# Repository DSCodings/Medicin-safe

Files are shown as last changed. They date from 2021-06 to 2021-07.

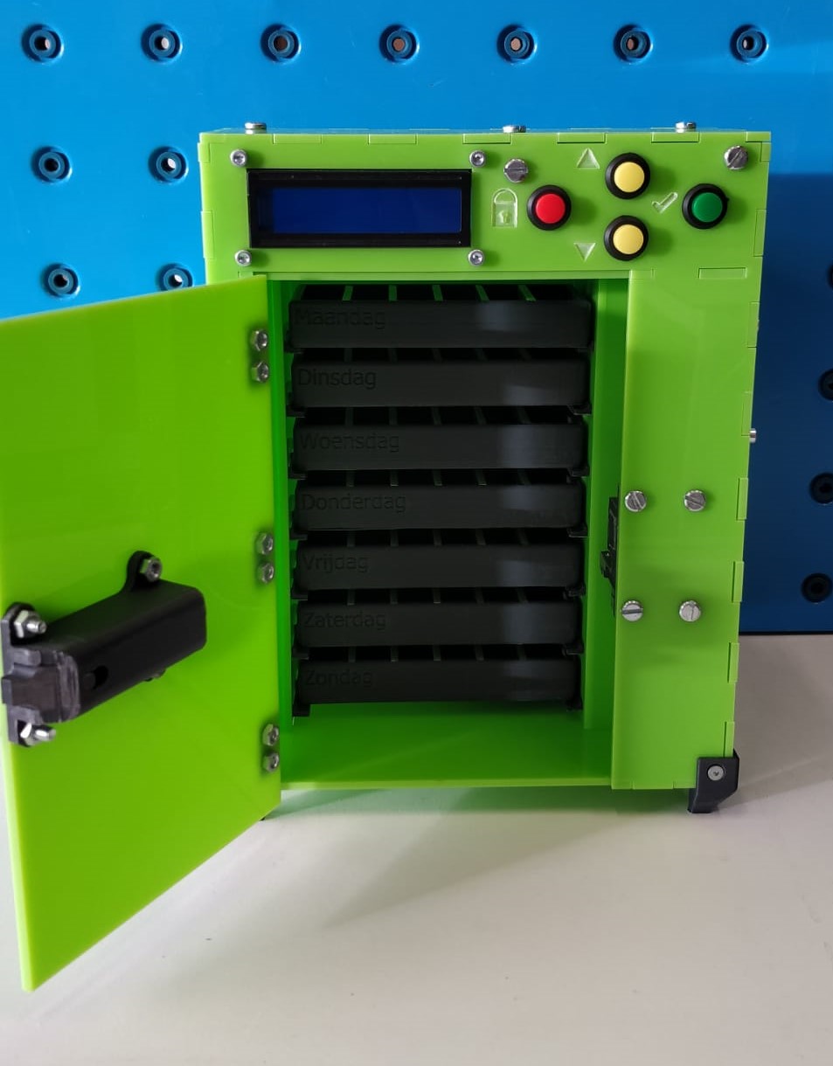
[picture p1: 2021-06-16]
English/photos/Foto1.jpeg

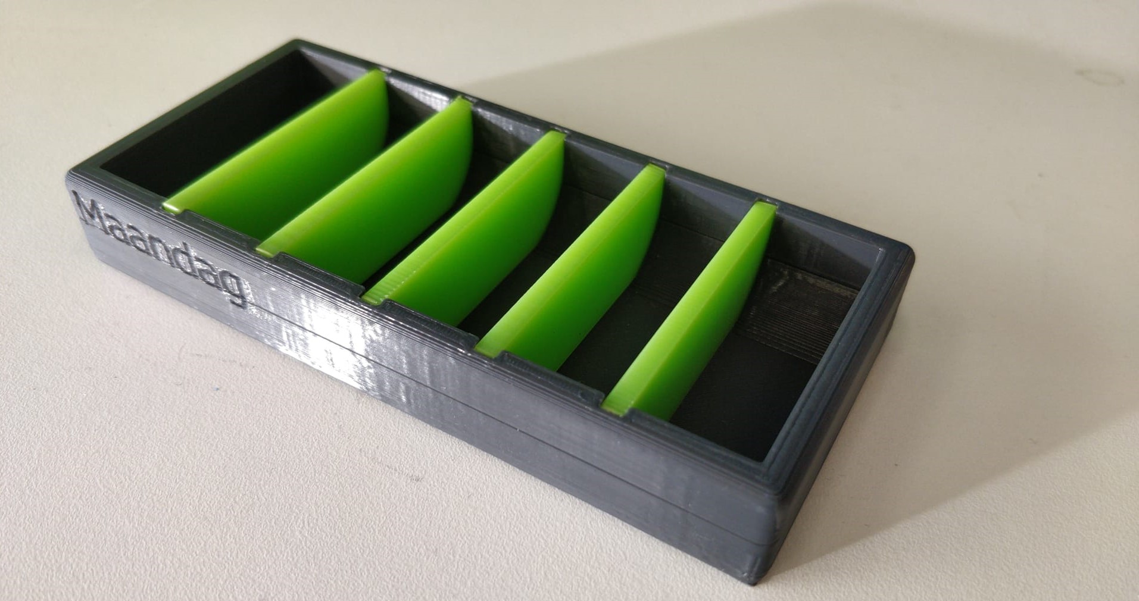
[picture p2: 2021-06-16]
English/photos/Foto3.jpeg

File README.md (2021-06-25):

# Medicijnenkluisje
Het project van een medicijnen kluisje dat gemaakt is in school. 
Je kan alle informatie vinden van stappenplan tot elektrisch schema tot video's wat het is.
Je kan de video's hier vinden:
https://www.youtube.com/watch?v=T6DbwzbS6sM
https://www.youtube.com/watch?v=bsVCNl2Fkfo

The project of a medicine locker made in school.
You can find all information from step-by-step plan to electrical diagram to videos what it is.
You can find the videos here:
https://www.youtube.com/watch?v=T6DbwzbS6sM
https://www.youtube.com/watch?v=bsVCNl2Fkfo

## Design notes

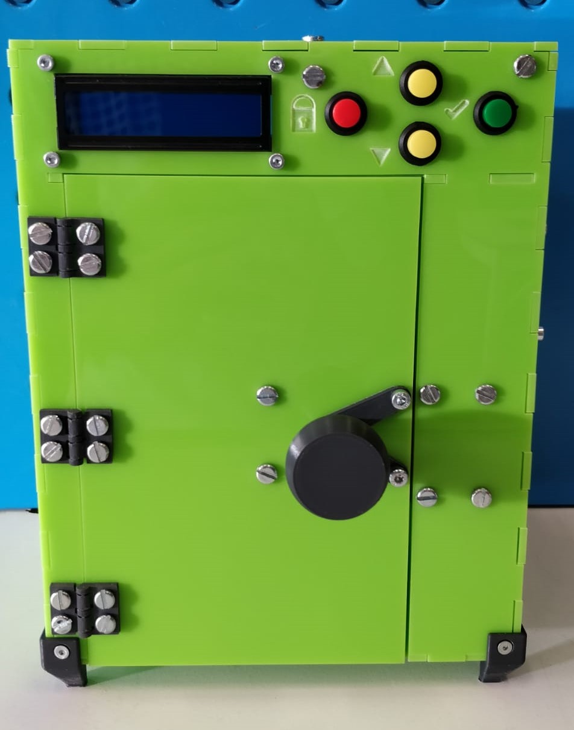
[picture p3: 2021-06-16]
English/photos/Foto2.jpeg

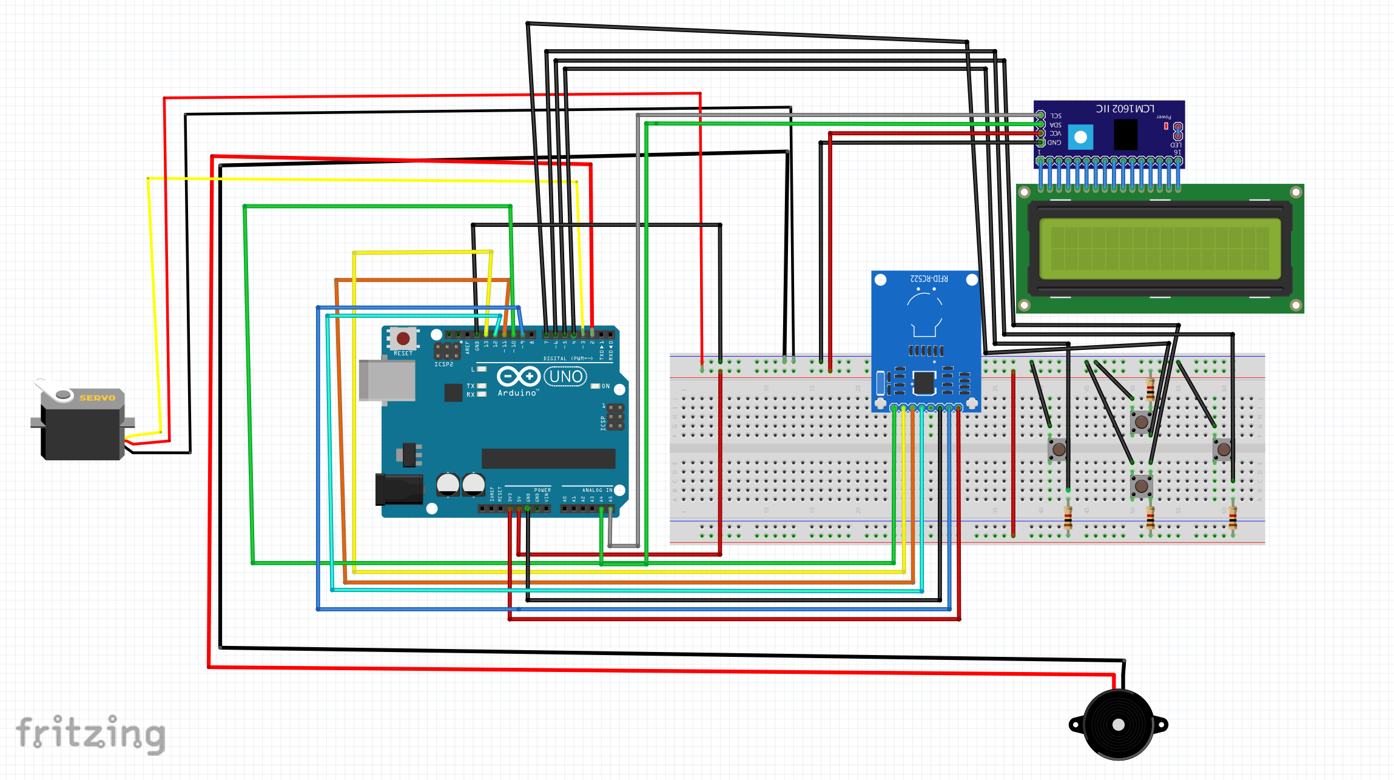
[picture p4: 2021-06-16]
English/electric scheme/Elektric scheme.png

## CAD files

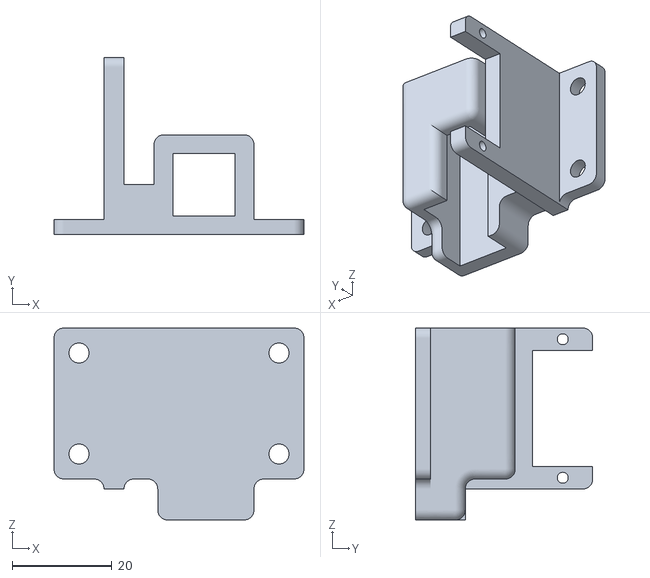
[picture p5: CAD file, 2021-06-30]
English/Files/3D printer STL files/16 slot servo holder.stl
50.0 x 35.5 x 38.4

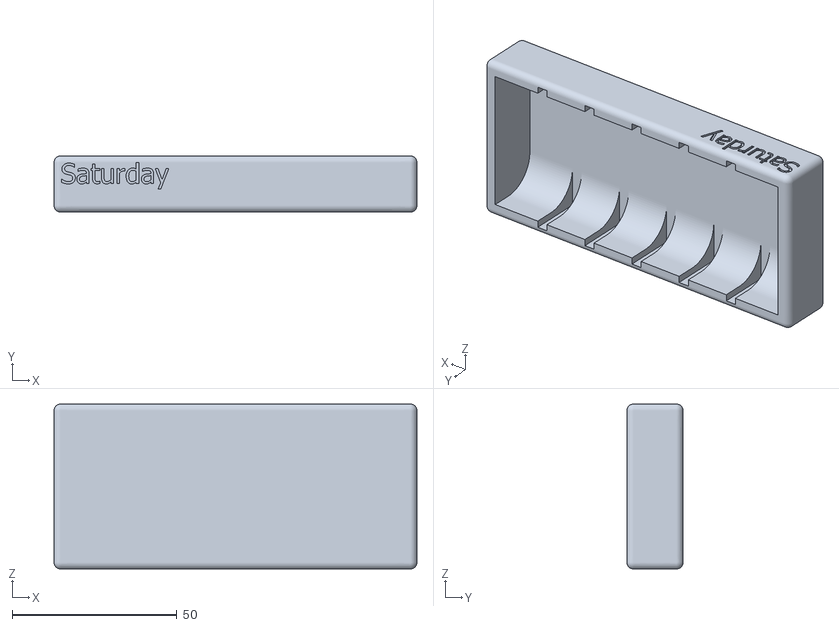
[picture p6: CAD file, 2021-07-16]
English/Files/3D printer STL files/Trays/Saturday.stl
110.0 x 17.0 x 50.0

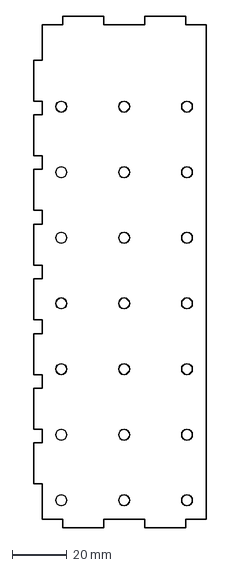
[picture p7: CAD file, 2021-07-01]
English/Files/Lazer DXF files/2 inner side plate.dxf
63.0 x 187.0 mm

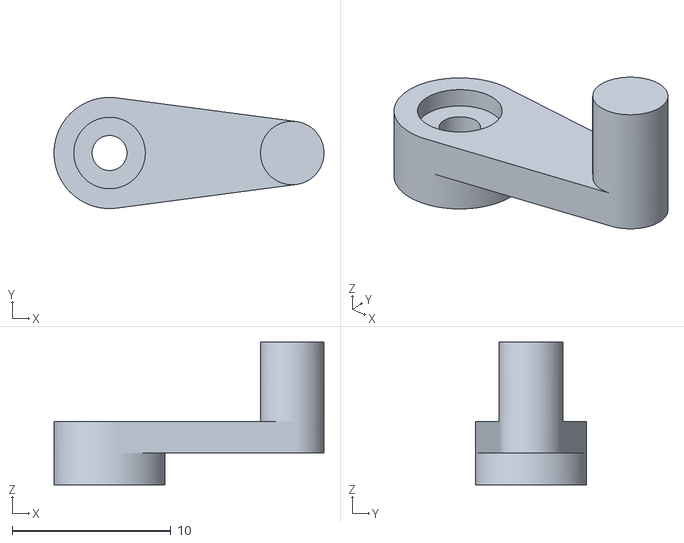
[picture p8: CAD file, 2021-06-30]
Nederlands/Bestanden/3D printer STL files/27 servo arm.stl
17.0 x 7.00 x 9.00

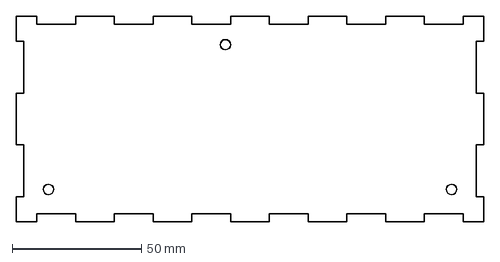
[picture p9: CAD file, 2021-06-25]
Nederlands/Bestanden/Lazer DXF files/12 boven plaat LCD.dxf
181.0 x 79.5 mm

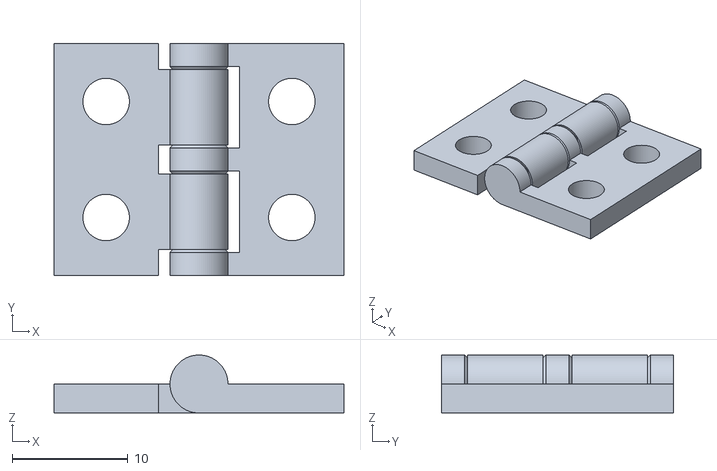
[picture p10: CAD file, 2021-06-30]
English/Files/3D printer STL files/26 hinge 0.2mm clearance.stl
25.0 x 20.0 x 5.00

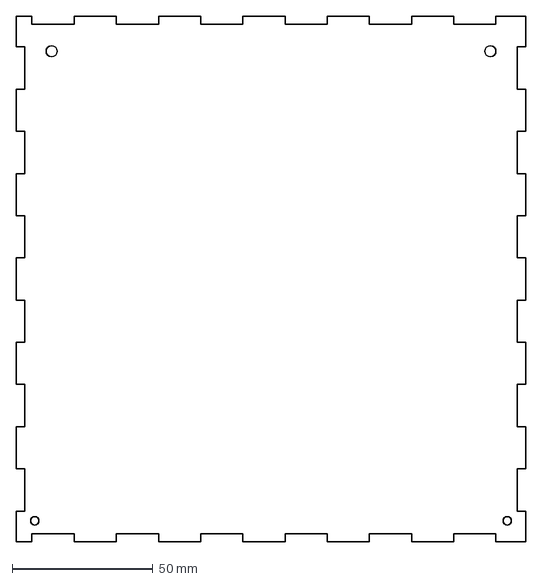
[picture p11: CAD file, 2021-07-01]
English/Files/Lazer DXF files/7 behind plate.dxf
181.0 x 187.0 mm

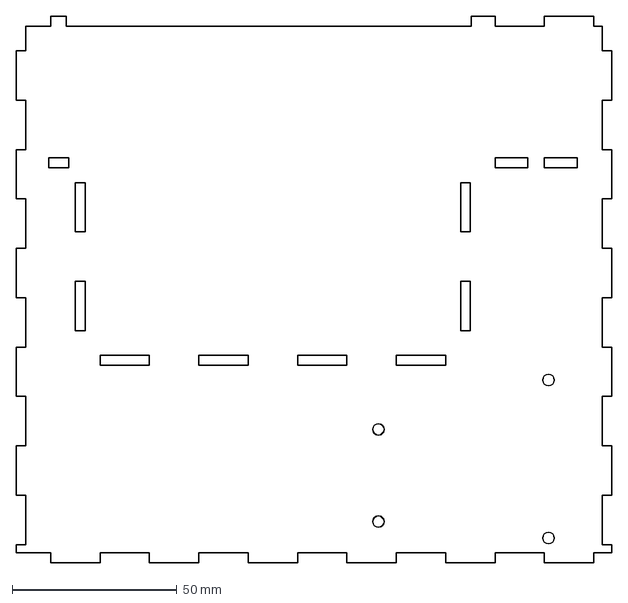
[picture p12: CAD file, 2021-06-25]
Nederlands/Bestanden/Lazer DXF files/5 onder plaat.dxf
181.0 x 166.0 mm

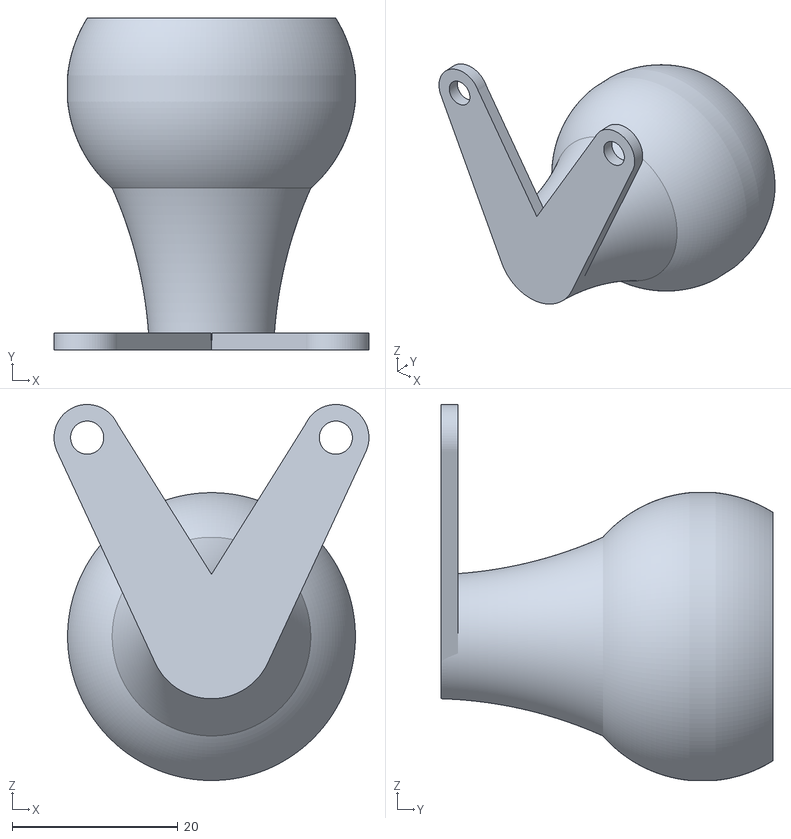
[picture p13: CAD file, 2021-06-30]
English/Files/3D printer STL files/25 door handle.stl
38.0 x 40.0 x 45.4

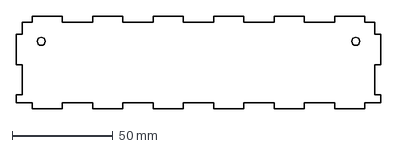
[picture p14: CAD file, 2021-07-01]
English/Files/Lazer DXF files/13 back plate LCD.dxf
181.0 x 46.0 mm

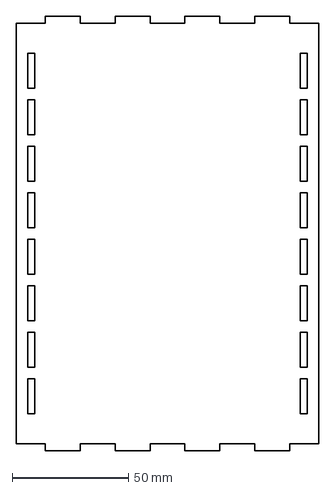
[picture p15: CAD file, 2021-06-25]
Nederlands/Bestanden/Lazer DXF files/1 binnen achter plaat.dxf
130.0 x 187.0 mm

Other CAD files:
Nederlands/Bestanden/3D printer STL files/Bakjes/Dinsdag.stl
English/Files/3D printer STL files/Trays/Sunday.stl
Nederlands/Bestanden/3D printer STL files/Bakjes/Zaterdag.stl
English/Files/3D printer STL files/Trays/Wednesday.stl
Nederlands/Bestanden/3D printer STL files/Bakjes/Woendag.stl
English/Files/3D printer STL files/26.2 hinge 0.3 mm clearance.stl
English/Files/3D printer STL files/Trays/Thursday.stl
English/Files/3D printer STL files/14 lock pin sleeve large.stl
English/Files/3D printer STL files/15 lock pin sleeve smal.stl
English/Files/3D printer STL files/17 lock counter pin.stl
English/Files/3D printer STL files/18 pin shooter.stl
English/Files/3D printer STL files/19 tray shelf.stl
English/Files/3D printer STL files/22 leg mounting corners.stl
English/Files/3D printer STL files/22.1 mounting brackets instead of bolts.stl
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

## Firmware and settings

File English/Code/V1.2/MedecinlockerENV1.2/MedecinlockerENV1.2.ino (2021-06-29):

/*
  -------------------------------------------------- -------------------------------------------------- ----------------
  medicine locker
  -------------------------------------------------- -------------------------------------------------- ----------------

   @author Sem Boonen and Daan Swinters
   @creator Daan Swinters
   @license Forbidden to use without permission of the authors.
  -------------------------------------------------- -------------------------------------------------- ----------------
  The connections on arduino(UNO):
  -------------------------------------------------- ---------------------------------------
                MFRC522      Arduino
                Reader/PCD   Uno/101
    Signaal     Pin          Pin
    -----------------------------------------------------------------------------------------
    RST/Reset   RST          9
    SPI SS      SDA(SS)      10
    SPI MOSI    MOSI         11 / ICSP-4
    SPI MISO    MISO         12 / ICSP-1
    SPI SCK     SCK          13 / ICSP-3

                LCD_I2C      Arduino
                Reader/PCD   Uno/101
    Signaal     Pin          Pin
    -----------------------------------------------------------------------------------------
    SPI SS      SDA(SS)      A4
    SPI SCL     SCL          A5

                Servo
    Signaal     Pin          Pin
    -----------------------------------------------------------------------------------------
    pwm         pwm          3

                Buzzer
    Signaal     Pin          Pin
    -----------------------------------------------------------------------------------------
    pin3        pin3          3


                knoppen
                Uno/101
    sinnaal     pin
    ------------------------------------------------------------------------------------------
    btnboven    7
    btnonder    5
    btnliks     4
    btnrechs    6

   © Sem Boonen and Daan Swinters Medicine safe 2021.
*/



#include "sleutel.h" //  This is a homemade libary where you can all store keys.
#include "tijdvooropenen.h" //  This is a homemade libary where you can all store keys.

#include <Servo.h> //  the servo libary.
Servo s3; // Add a servo with the name.


#include <Wire.h>  // for communicating with the I2C screen.
#include <LiquidCrystal_I2C.h> // for the to print on the i2c.

// Set the LCD address to 0x27 for a 16-character, 2-line display.
LiquidCrystal_I2C lcd(0x27, 16, 2);



#include <MsTimer2.h> // the timer for every second 



#include <SPI.h> // for the to communicate with the rfid.
#include <RFID.h>
#define SS_PIN 10 // the pins define rfid.
#define RST_PIN 9
RFID rfid(SS_PIN, RST_PIN);
String rfidCard; // of rfidcard code
String Data55; // here in is stored every time the safe is opened for nurse.
String Data1 = "Verpleger: ";

String Data66;// It stores every time the box is opened for the patient.
String Data2 = "Patient: ";


String versie = "v1.2"; // the version of the medicine safe.


int schrikkeljaar = 2020; // first leap year set(the day/month/year given at the start).
int dag = 1; //  // days
int maand = 1; // months
int jaar = 2020; // years


int h = 0; // hours
int m = 0; //  minutes
int s = 0; //  seconds

int mmedicijn = 0;

int Li = 16; // view scroll to the left
int Lii = 0;


int servotimer = 0; // the timer for closing the door back is set to 0 at the start.
int gradenservodict = 90; // the degrees for the servo close.
int gradenservoopen = 15; // the degrees for the servo close.
int hoelangopen = 30; // How many seconds the door must be open.



const int buttonboven = 7;  // pins of the 4 buttons
const int buttonrechts = 6;
const int buttononder = 5;
const int buttonlinks = 4;

bool updatetime = false; // time updater(happens 1 time per second).
bool accesaccepted = false; // If you have access as a nurse.
bool datechange = false; //before changing the date.
bool datechange2 = false;
bool timechange = false; // for the time to change
bool Time = false;
bool seth = false; // change the hours.
bool setm = false; // change the minutes
bool pijl = false; // the arrow shown at the time change.
bool achtergrond = false; // change background lighting.
bool achtergrond1 = true; // if the backlight is on or off.
bool achtergrond2 = false; // change background lighting.
bool controldata = false; // of date controleren
bool controldata1 = false;
bool setjaar = false; // change years
bool setmaand =  false; // month change
bool setdag = false; // days change.
bool voegopeneningstijdentoe = false; // for the times to open set.
bool voegopeneningstijden2toe = false;
bool verwijderopeneningstijdentoe = false; // for the times to open set.
bool verwijderopeneningstijden2toe = false;

int hopeningtijden = 0; // for opening hours.
int mopeningtijden = 0; // for opening minutes.
int sopeningtijden = 0; // for opening seconds.
bool sethopeningstijden = false; // for the hours to change.
bool setmopeningstijden = false; // voor de minuten te veranderen.
bool vergrendelingvoortijdstip = false; // If the nurse wants to set when the patient can only open the locker it is time.
bool vergrendelingvoortijdstip2 = false;
bool vergrendelingvoortijdstip1 = false; // if this is set to false then the patient can always open it otherwise not, defaults to false.
bool bekijktijden = false; // for to see what hours have been set.
bool bekijktijden1 = false;

bool heeftmedicijngenomen = true; // if the patient has taken his medicine or not.

bool addrfid = false;//add nurse rfid 
bool addrfid2 = false;
bool addrfid3 = false;//add rfid patient .
bool addrfid4 = false;

bool removerfid = false;//removal rfid nurse .
bool removerfid2 = false;
bool removerfid3 = false;// removal rfid patient.
bool removerfid4 = false;

bool buzzeron = false; // if the buzzer is on or not.
bool buzzeron2 = false;

bool schermvergrendeling = false; // screen on or off when locked.
bool schermvergrendeling2 = false;
bool schermvergrendelingaanuit = true; // the screen should be on or off at the time of the lockout

bool deuropenclose = false; // is the door open or closed.


SleutelStore sleutelsPatienten; // keeps the patient's keyals.
SleutelStore sleutelsVerpleger; // Keeps the keys from the nurse.

TijdStore Tijdenvooropenen; //saves the times for opening


void setup() {
  
  MsTimer2::set(1000, countDownOneSecond);  // every 1000ms it calls the function for the time.
  MsTimer2::start(); // the timer is started.

  Serial.begin(9600); // start the serial port.

  

  char masterCard[] = "9 160 86 211"; // The map where you can add keys(main card).
  char Card1[] = "12 177 28 181";     // Add another card;
   
  sleutelsVerpleger.voegHoofdSleutelToe(masterCard);// add the main card.
  
  sleutelsPatienten.voegSleutelToe(Card1); // Adds a card for the nurse.
  sleutelsPatienten.voegSleutelToe(masterCard); // adds a card for the patient.
  sleutelsVerpleger.printSleutels(); // Print all keys that have access.
  sleutelsPatienten.printSleutels();

  Serial.println("Starting the RFID Reader...");
  SPI.begin(); // the rfid reader is started.
  rfid.init();
  lcd.begin(); // the lcd is booted.
  lcd.clear();
  lcd.print("Medicine safe"); // startup screen
  lcd.setCursor(0, 1);
  lcd.print(versie);
  lcd.setBacklight(HIGH); // set the backlight to high on lcd.


  pinMode(2, OUTPUT); //output for the buzzer / makes a sound at the start.
  for (int i = 0; i <= 3; i++) { // this he repeats 3 times, it goes on, off on.
    if (buzzeron == false) { // when it's off it goes on
      digitalWrite(2, HIGH); // set the gate high.
      delay(150); // wait 150 milliseconds
      buzzeron = true; // set the bool to true.
    }
    else { // otherwise
      digitalWrite(2, LOW); // Set the buzzer low.
      delay(150); // wait 150 milliseconds
      buzzeron = false; //set it to false.
    }

  }

  digitalWrite(2, HIGH); // set it high.


  delay(500); // wait 500 milliseconds.
  digitalWrite(2, LOW); // Set it low.

  buzzeron = false;
  // the hours/minutes/seconds are set to 0.
  h = 0; // hours
  m = 0; //  minutes
  s = 0; //  seconden
  
  pinMode(buttonboven, INPUT); // the top button
  pinMode(buttonrechts, INPUT); // the right button
  pinMode(buttononder, INPUT); // the bottom button
  pinMode(buttonlinks, INPUT); // the left button
  Serial.println("TIME:" ); // print the time in the serial port.
  Serial.println(h);
  Serial.println(":");
  Serial.println(m);
  Serial.println(":");
  Serial.println(s);





  s3.attach(3); // set the servo to the correct position.
  s3.write(gradenservodict);




  lcd.clear();
  lcd.print(String(h, DEC)); // prints the time on the LCD at startup, the string h is set up in decimal places.
  lcd.print(":");
  lcd.print(String(m, DEC));// prints the time on the LCD at startup, the string m is set up in decimal places.
  lcd.print(":");
  lcd.print(String(s, DEC));// prints the time on the LCD at startup, the string s is set up in decimal places.

}
void countDownOneSecond() {

  s = s + 1; // Every second adds a second.


  if (s == 60) // Every 60 seconds, a minute is added.
  {
    s = 0; // resets the seconds to 0.
    m = m + 1; // when there are 60 seconds a Minute is added.
    mmedicijn = mmedicijn + 1; // the timer is up-dated. one is added every minute.
  }
  if (m == 60) // when there are 60 minutes an hour is added.
  {

    m = 0; // the mintues are reset to zero

    h = h + 1; // the hour is added 1.

  }
  if (h == 24)
  {
    h = 0; // the hours are set to 0.
    dag = dag + 1; //  Every 24h a day is added.
  }
  updatetime = true; // every second the time is then up-dated on the lcd.
  servotimer = servotimer + 1; // 1 second is added for how long the door remains open.




}

void printtime() {
  if (accesaccepted == false && schermvergrendelingaanuit == true) { // print the time.
    if (m < 10) {
      lcd.clear();

      lcd.print(String(h, DEC)); // print the time on the lcd
      lcd.print(":");
      lcd.print("0" + String(m, DEC)); // put an extra zero if the minutes are smaller 10.
      lcd.print(":");
      lcd.print(String(s, DEC));
    }
    else {
      lcd.clear();

      lcd.print(String(h, DEC)); //print the time on the LCD.
      lcd.print(":");
      lcd.print(String(m, DEC));
      lcd.print(":");
      lcd.print(String(s, DEC));
    }
    lcd.setCursor(0, 1); // put the cursor on the 2nd line.
    lcd.print(String(dag, DEC)); // Print the date below the time.
    lcd.print("/");
    lcd.print(String(maand, DEC));
    lcd.print("/");
    lcd.print(String(jaar, DEC));


  }
  if (achtergrond1 == true) { // turn background verliting on or off, if the screen is off when locked.
    if (schermvergrendelingaanuit == false) { // if lockout should be off
      if (accesaccepted == false) { // if there is no access.
        lcd.setBacklight(LOW); // turns off the light of the lcd.
      }
      else {
        lcd.setBacklight(HIGH); //otherwise it stands ON
      }
    }
    else {
      lcd.setBacklight(HIGH); // backlight ON
    }
  }
  else {
    lcd.setBacklight(LOW); // backlight OFF
  }

}

void opendeur() { // opens the servo door.
  servotimer = 0; // set the timer to 0;
  s3.write(gradenservoopen); // set the servo to the degrees for opening.
}

void scrolldisplay() { // Print when the patient has opened the safe.
  if (Data66 == "") { // if the data is empty then it prints "/".
    Data66 = " /";
  }

  if (Data55 == "") {
    Data55 = " /";
  }

  delay(100); // scrolls the display to the left.
  lcd.scrollDisplayLeft();
  delay(100);
  lcd.scrollDisplayLeft();
  delay(100);
  lcd.scrollDisplayLeft();
  delay(100);
  lcd.scrollDisplayLeft();
  delay(100);
  lcd.scrollDisplayLeft();
  delay(100);
  lcd.scrollDisplayLeft();
  delay(100);
  lcd.scrollDisplayLeft();
  delay(100);
  lcd.scrollDisplayLeft();
  delay(100);
  lcd.scrollDisplayLeft();
  delay(100);
  lcd.scrollDisplayLeft();


  if (Data66 == "/") { // if the data was empty it becomes empty again.
    Data66 = "";
  }

  if (Data55 == "/") {
    Data55 = "";
  }

}





byte customChar[] = { // change the arrow for the time, costum charachter
  B00100, // for the 1st row, 0 is the light off and 1 is the light on.
  B01110, // for the 2st row, 0 is the light off and 1 is the light on.
  B11111, // for the 3st row, 0 is the light off and 1 is the light on.
  B00100, // for the 4st row, 0 is the light off and 1 is the light on.
  B00100, // for the 5st row, 0 is the light off and 1 is the light on.
  B00100, // for the 6st row, 0 is the light off and 1 is the light on.
  B00100, // for the 7st row, 0 is the light off and 1 is the light on.
  B00100  // for the 8st row, 0 is the light off and 1 is the light on.
};
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
void loop() { // is repeated infinitely.

  if (vergrendelingvoortijdstip1 == true && (Tijdenvooropenen.istijdstipgelijk((String(h) + ":" + String(m)  + ":"  + String(s)).c_str()) == true)) { // if the hours and minutes are equal to the set hours and minutes and the patient cannot open the safe before.
    mmedicijn = 0; // wordt terug gereset.
    heeftmedicijngenomen = false; // this is set to false because the patient has not yet taken any medicine
    digitalWrite(2, HIGH); // turn on the buzzor.
    //delay(300);

  }
  else { // otherwise
    //delay(300);
    digitalWrite(2, LOW); // turn off the buzzer.

  }

  if (heeftmedicijngenomen == false) { // als hij nog geen medicijn heeft genomen, dan biept hij om de 10 min.
    if (vergrendelingvoortijdstip1 == true && (mmedicijn == 10 || mmedicijn == 20 || mmedicijn == 30 || mmedicijn == 40 || mmedicijn == 50 || mmedicijn == 60 || mmedicijn == 70 || mmedicijn == 80 || mmedicijn == 90 || mmedicijn == 100 || mmedicijn == 110 || mmedicijn == 120 || mmedicijn == 130 || mmedicijn == 140 || mmedicijn == 150 || mmedicijn == 160 || mmedicijn == 170 || mmedicijn == 180 || mmedicijn == 190 || mmedicijn == 200 || mmedicijn == 210 || mmedicijn == 220 || mmedicijn == 230 || mmedicijn == 240 || mmedicijn == 250))
// Every 10 minutes the buzzer turns on.
      
      digitalWrite(2, HIGH); // turn on the buzzer.
    delay(1000);

    

  }

  if (hopeningtijden < 0){
    hopeningtijden = 0;
 }
 if (mopeningtijden < 0){
    mopeningtijden = 0;
 }

  if (maand == 1) { // the month/year/day is changed automatically.
    if (dag == 32) { // if the there are too many days in the month then a month is added and the day becomes 1 again.
      maand = maand + 1; // month is added.
      dag = 1; // day becomes back 1
    }
  }
  else if (maand == 2) { // if it is the 2nd month is also checked for a leap year.
    if (schrikkeljaar == jaar || schrikkeljaar + 4 == jaar || schrikkeljaar + 8 == jaar || schrikkeljaar + 12 == jaar || schrikkeljaar + 16 == jaar || schrikkeljaar + 20 == jaar || schrikkeljaar + 24 == jaar || schrikkeljaar + 28 == jaar || schrikkeljaar + 32 == jaar) {
      if (dag == 30) { // if the there are too many days in the month then a moon is added and the day becomes 1 again.
        maand = maand + 1; // month is added.
        dag = 1; // The day will be back 1.
      }
    }
    else {
      if (dag == 29) { // if the there are too many days in the month then a month is added and the day becomes 1 again.
        maand = maand + 1; // month is added.
        dag = 1; // The day will be back 1.
      }
    }
  }
  else if (maand == 3) { // als het de 3de maand is.
    if (dag == 32) { // if the there are too many days in the month then a month is added and the day becomes 1 again.
      maand = maand + 1; // er wordt  maand bijgeteld.
      dag = 1; // De dag wordt terug 1.
    }
  }
  else if (maand == 4) { //If it is the 4th month.
    if (dag == 31) { // if the there are too many days in the month then a month is added and the day becomes 1 again.
      maand = maand + 1; // month is added.
      dag = 1; // The day turns back 1.
    }
  }
  else if (maand == 5) { // if it is the 5th month.
    if (dag == 32) { // if the there are too many days in the month then a month is added and the day becomes 1 again.
      maand = maand + 1; // there is month added.
      dag = 1; // The day becomes back 1.
    }
  }
  else if (maand == 6) { // if it is the 6th month.
    if (dag == 31) { // if the there are too many days in the month then a month is added and the day becomes 1 again.
      maand = maand + 1; // month is added.
      dag = 1; // The day turns back 1.
    }
  }
  else if (maand == 7) { // if it is the 7th month.
    if (dag == 32) { // if the there are too many days in the month then a month is added and the day becomes 1 again.
      maand = maand + 1; // month is added.
      dag = 1; // The day turns back 1.
    }
  }
  else if (maand == 8) { // if it is the 8th month.
    if (dag == 32) { // if the there are too many days in the month then a month is added and the day becomes 1 again.
      maand = maand + 1; // month is added.
      dag = 1; // The day will be back 1.
    }
  }
  else if (maand == 9) { // if it is the 9th month.
    if (dag == 31) { // if the there are too many days in the month then a month is added and the day becomes 1 again.
      maand = maand + 1; // month is added.
      dag = 1; // The day turns back 1.
    }
  }
  else if (maand == 10) { // if it is the 10th month.
    if (dag == 32) { // if the there are too many days in the month then a month is added and the day becomes 1 again.

      maand = maand + 1; // there is month added.
      dag = 1; // The day becomes back 1.
    }
  }
  else if (maand == 11) { // if it is the 11th month.
    if (dag == 31) { // if the there are too many days in the month then a month is added and the day becomes 1 again.
      maand = maand + 1; // one month is added.
      dag = 1; // The day turns back 1.
    }
  }
  else if (maand == 12) { // if it is the 12 month.
    if (dag == 32) { // if the there are too many days in the month then a month is added, a yeart and the day and month become 1.
      maand = 1; // The month will be back 1.
      dag = 1; // The day turns back 1.
      jaar = jaar + 1; // one year is added.
    }
  }

  if (servotimer > hoelangopen && deuropenclose == true) { //the door will be closed
    s3.write(gradenservodict); // the servo is set to 0 degrees.
    deuropenclose = false; 
    servotimer = 0; // the servo timer is reset.
  }
  if (deuropenclose == true){ // when the door is closed in it stays closed.
      s3.write(gradenservoopen);
   }
    else{ // when the door is open it stays open.
      s3.write(gradenservodict);
   }



  if (accesaccepted == false) { // if the screen is to be off when locked, the backlight goes off.
    if (schermvergrendelingaanuit == false) {
      lcd.clear(); // the screen is emptied.
      lcd.setBacklight(LOW); // Backlight is turned off.
    }


  }
  if (achtergrond1 == true) { // when the backlight is on.
    if (schermvergrendelingaanuit == false) { // and the screen when locked is off.
      if (accesaccepted == false) { // and that there is no access.
        lcd.setBacklight(LOW); // background lighting off;
      }
      else { //If there is access.
        lcd.setBacklight(HIGH); // background lighting on.
      }
    }
    else { // If the screen is on when locked.
      lcd.setBacklight(HIGH); // background lighting is on.
    }
  }
  else { // when the backlight is off.
    lcd.setBacklight(LOW); // backlight is off;
  }
  if ((controldata1 == true || bekijktijden1 == true) && updatetime == true) { // if the menu control is open and timer is updated.

    scrolldisplay(); // scrolls the screen with the data.


  }


  if (updatetime == true) { // update de timer/
    printtime();   // print the time and print the date.
    printtime1();  // print the time when it is changed.
    printtime2();
    datumchange(); // change the date
    updatetime = false; // the time is updated.

  }


  if (digitalRead(buttonboven) == LOW) { // when the top button is pressed.
    Serial.println("buttonboven");
    delay(300);

    if (setdag == true) { // change day
      dag = dag + 1; // add a day.
    }
    else if (setmaand == true) { // month change
      maand = maand + 1; // one month is added
    }
    else if (setjaar == true) { // year change
      jaar = jaar + 1; // one year is added.
    }

    else if (timechange == true) { // when you see the word time on the main menu.
      datechange = true; // for the date to change
      timechange = false; // for the time to change
      lcd.clear();
      lcd.print("Date"); // print Date;
    }
    else if (removerfid3 == true) { // if the nurse wants to add an opening time.
      removerfid3 = false; // put the bools right.
      voegopeneningstijdentoe = true;
      lcd.clear(); // print what should be on the screen.
      lcd.print("Add Opening");
      lcd.setCursor(0, 1);
      lcd.print("Time");


    }
    else if (vergrendelingvoortijdstip == true) { // if you want to go to the menu to see the opening hours.
      vergrendelingvoortijdstip = false; // set the bools correctly.
      bekijktijden = true;
      lcd.clear(); // print the right one on the screen.
      lcd.print("View Opening");
      lcd.setCursor(0, 1);
      lcd.print("Times");
    }
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

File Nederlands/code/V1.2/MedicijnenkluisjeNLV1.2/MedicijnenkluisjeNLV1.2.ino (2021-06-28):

/*
  --------------------------------------------------------------------------------------------------------------------
  Medicijnekluisje
  --------------------------------------------------------------------------------------------------------------------
  Project Medicijnekluisje voor MSReva in pelt.
  --------------------------------------------------------------------------------------------------------------------
  Dit is een project voor het controleren van gebruik van medicijnen.

   @author Sem Boonen en Daan Swinters
   @creator Daan Swinters
   @license Verboden te gebruiken zonder toestemming van de auteurs.
  --------------------------------------------------------------------------------------------------------------------
  De aansluitingen op arduino(UNO):
  -----------------------------------------------------------------------------------------
                MFRC522      Arduino
                Reader/PCD   Uno/101
    Signaal     Pin          Pin
    -----------------------------------------------------------------------------------------
    RST/Reset   RST          9
    SPI SS      SDA(SS)      10
    SPI MOSI    MOSI         11 / ICSP-4
    SPI MISO    MISO         12 / ICSP-1
    SPI SCK     SCK          13 / ICSP-3

                LCD_I2C      Arduino
                Reader/PCD   Uno/101
    Signaal     Pin          Pin
    -----------------------------------------------------------------------------------------
    SPI SS      SDA(SS)      A4
    SPI SCL     SCL          A5

                Servo
    Signaal     Pin          Pin
    -----------------------------------------------------------------------------------------
    pwm         pwm          3

                Buzzer
    Signaal     Pin          Pin
    -----------------------------------------------------------------------------------------
    pin3        pin3          3


                knoppen
                Uno/101
    sinnaal     pin
    ------------------------------------------------------------------------------------------
    btnboven    7
    btnonder    5
    btnliks     4
    btnrechs    6

   © Sem Boonen en Daan Swinters Medicijnekluisje 2021.
*/



#include "sleutel.h" //  Dit is een zelfgemaakte libary waar je allen sleutels kan bewaren.
#include "tijdvooropenen.h" //  Dit is een zelfgemaakte libary waar je allen sleutels kan bewaren.

#include <Servo.h> //  de servo libary.
Servo s3; // een servo toevoegen met de naam.


#include <Wire.h>  // voor te communiceren met het I2C scherm.
#include <LiquidCrystal_I2C.h> // voor de te printen op de i2c.

// Stel het LCD-adres in op 0x27 voor een display met 16 tekens en 2 regels.
LiquidCrystal_I2C lcd(0x27, 16, 2);



#include <MsTimer2.h> // de timer voor elke second 



#include <SPI.h> // voor de te communiceren met de rfid.
#include <RFID.h>
#define SS_PIN 10 // de pinnen defineren rfid.
#define RST_PIN 9
RFID rfid(SS_PIN, RST_PIN);
String rfidCard; // de rfidcard code
String Data55; // hier in word elke keer opgeslagen wanneer het kluisje word geopend voor verpleger.
String Data1 = "Verpleger: ";

String Data66;// hier in word elke keer opgeslagen wanneer het kluisje word geopend voor patient.
String Data2 = "Patient: ";


String versie = "v1.2"; // de versie van het medicijne kluisje.


int schrikkeljaar = 2020; // eerste schrikkeljaar dat is ingesteld(de dag/maand/jaar dat bij het begin wordt gegeven.)
int dag = 1; //  // dagen
int maand = 1; // maanden
int jaar = 2020; // jaren


int h = 0; // uren
int m = 0; //  minuten
int s = 0; //  seconden

int mmedicijn = 0;

int Li = 16; // display naar links scrollen
int Lii = 0;


int servotimer = 0; // de timer voor de deur terug te sluiten, wordt bij het begin op 0 gezet.
int gradenservodict = 90; // de graden voor de servo dicht.
int gradenservoopen = 15; // de graden voor de servo open.
int hoelangopen = 30; // hoeveel seconden de deur moet open zijn.



const int buttonboven = 7;  // pins van de 4 knoppen
const int buttonrechts = 6;
const int buttononder = 5;
const int buttonlinks = 4;

bool updatetime = false; //  tijd updaten.
bool accesaccepted = false; // Als je toegang hebt als verpleger.
bool datechange = false; //voor de datum te veranderen.
bool datechange2 = false;
bool timechange = false; // voor de tijd te veranderen
bool Time = false;
bool seth = false; // de uren veranderen.
bool setm = false; // de minuten veranderen
bool pijl = false; // de pijl die wordt getoond bij de tijd te veranderen.
bool achtergrond = false; // achtergrond verlichting veranderen.
bool achtergrond1 = true; // als de achtergrond verlichting aan of uit is.
bool achtergrond2 = false; // achtergrond verlichting veranderen.
bool controldata = false; // de data controleren
bool controldata1 = false;
bool setjaar = false; // jaar veranderen
bool setmaand =  false; // maand veranderen
bool setdag = false; // dagen veranderen.
bool voegopeneningstijdentoe = false; // voor de tijden te openen in te stellen.
bool voegopeneningstijden2toe = false;
bool verwijderopeneningstijdentoe = false; // voor de tijden te openen in te stellen.
bool verwijderopeneningstijden2toe = false;

int hopeningtijden = 0; // voor de uren voor het openen.
int mopeningtijden = 0; // voor de minuten voor het openen.
int sopeningtijden = 0; // voor de seconden voor het openen.
bool sethopeningstijden = false; // voor de uren te veranderen.
bool setmopeningstijden = false; // voor de minuten te veranderen.
bool vergrendelingvoortijdstip = false; // Als de verpleger wilt instellen als de patient het kluisje pas kan openen het tijd is.
bool vergrendelingvoortijdstip2 = false;
bool vergrendelingvoortijdstip1 = false; // als dit op false is dan kan de patient het altijd openen anders niet, staat standaart op false.
bool bekijktijden = false; // voor te bekijken welke uren zijn ingesteld.
bool bekijktijden1 = false;

bool heeftmedicijngenomen = true; // als de patient zijn medicijn heeft genomen of niet.

bool addrfid = false;//verpleger rfid toevoegen
bool addrfid2 = false;
bool addrfid3 = false;//patient patient toevoegen.
bool addrfid4 = false;

bool removerfid = false;//rfid verpleger verwijderen.
bool removerfid2 = false;
bool removerfid3 = false;//rfid patient verwijderen.
bool removerfid4 = false;

bool buzzeron = false; // als de buzzer aan is is dit waar.
bool buzzeron2 = false;

bool schermvergrendeling = false; // scherm aan of uit bij vergrendeling.
bool schermvergrendeling2 = false;
bool schermvergrendelingaanuit = true; // het scherm aan of uit moet zijn bij de bergrendeling

bool deuropenclose = false; // is de deur open of dicht.


SleutelStore sleutelsPatienten; // bewaart de sleutals van de patient.
SleutelStore sleutelsVerpleger; // bewaart de sleutels van de verpleger.

TijdStore Tijdenvooropenen; //bewaart de tijden voor te openen.
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

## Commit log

2021-06-24 uploaded electric scheme
    [TIoschol.fzz]
2021-06-25 update files
    [1 binnen achter plaat.dxf, 10 voor plaat.dxf, 10.1 lock icon.dxf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]
2021-07-01 update translation
    [14 lock pin sleeve large.stl, 15 lock pin sleeve smal.stl]
2021-07-01 update language
    [16 slot servo holder.stl, 17 lock counter pin.stl, 18 pin shooter.stl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]
2021-07-16 update trays
    [Friday.ipt, Friday.stl, Monday.ipt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]
